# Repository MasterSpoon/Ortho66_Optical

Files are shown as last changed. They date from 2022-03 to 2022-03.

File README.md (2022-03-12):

# Ortho66_Optical
 Ortho 66 Optical PCB using KeyChron low profile optical switches
 
A member on Optical Future discord did trial fit of ir12-21 on switch and will be too close to use.
Took some measurements from a photo I found of a KeyChron PCB and appears they are using 0603 side view IR & PT
Managed to locate some and will need to redo PCB to suit.
Datasheets updated in resources.

This keyboard PCB is a work in progress and has been uploaded to share progress. Schmatic the PCB should be complete however the PCB will need to be updated with the new footprints for 0603 side IR and PT

The footprint's have not yet been tested and will likely be too close to fit correctly.
The code to support the matrix in QMK has not yet been written.
The MCU's are quite hard to obtain at the moment.
Feel free to do with it what you want but I would not suggest getting a PCB made based on the current version.

If you plan to use the footprints in an alternate design there are scripts under the resource folder that will place the supporting components in what I think should be the correct position. Look at the existing schematic for how each part should be named or you can also look at the scripts to get an idea on how they work.

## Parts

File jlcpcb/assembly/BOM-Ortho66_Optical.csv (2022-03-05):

Comment | Designator | Footprint | LCSC
BSS138 | Q1,Q10,Q11,Q12,Q13,Q14,Q2,Q3,Q4,Q5,Q6,Q7,Q8,Q9 | SOT-23 | C112239
100k | R50,R51,R55 | R_0805_2012Metric | C149504
10nF | C11 | C_0402_1005Metric | C15195
100nF | C1,C10,C14,C4,C6,C9 | C_0402_1005Metric | C1525
4.7nF | C13,C15 | C_0402_1005Metric | C1538
10uF | C16 | C_0402_1005Metric | C15525
TYPE-C-31-M12_13 | J1 | USB_C_Receptacle_TYPE-C-31-M-12 | C165948
10K | R47,R56 | R_0805_2012Metric | C17414
150 | R19,R21,R25,R27,R31,R35,R39,R41,R43,R45 | R_0805_2012Metric | C17471
1M | R54 | R_0805_2012Metric | C17514
20 | R1,R10,R11,R14,R15,R16,R17,R2,R5,R6,R7,R8 | R_0805_2012Metric | C17544
2K | R48,R49 | R_0805_2012Metric | C17604
300 | R20,R22,R23,R24,R26,R28,R29,R30,R32,R33,R34,R36,R37,R38,R40,R42,R44,R46 | R_0805_2012Metric | C17617
51 | R12,R13,R18,R3,R4,R9 | R_0805_2012Metric | C17738
4.7uF | C5 | C_0402_1005Metric | C23733
PT12-21B_TR8 | PT1,PT10,PT11,PT12,PT13,PT14,PT15,PT16,PT17,PT18,PT19,PT2,PT20,PT21,PT22,PT23,PT24,PT25,PT26,PT27,PT28,PT29,PT3,PT30,PT31,PT32,PT33,PT34,PT35,PT36,PT37,PT38,PT39,PT4,PT40,PT41,PT42,PT43,PT44,PT45,PT46,PT47,PT48,PT49,PT5,PT50,PT51,PT52,PT53,PT54,PT55,PT56,PT57,PT58,PT59,PT6,PT60,PT61,PT62,PT63,PT64,PT65,PT66,PT7,PT8,PT9 | PT12-21B_TR8 | C264383
USBLC6-2SC6 | U4 | SOT-23-6 | C2687116
5.1k | R52,R53 | R_0805_2012Metric | C27834
DTC123J | Q15 | SOT-23 | C406040
1uF | C12,C2,C3,C7,C8 | C_0402_1005Metric | C52923
IR12-21C_TR8 | IR1,IR10,IR11,IR12,IR13,IR14,IR15,IR16,IR17,IR18,IR19,IR2,IR20,IR21,IR22,IR23,IR24,IR25,IR26,IR27,IR28,IR29,IR3,IR30,IR31,IR32,IR33,IR34,IR35,IR36,IR37,IR38,IR39,IR4,IR40,IR41,IR42,IR43,IR44,IR45,IR46,IR47,IR48,IR49,IR5,IR50,IR51,IR52,IR53,IR54,IR55,IR56,IR57,IR58,IR59,IR6,IR60,IR61,IR62,IR63,IR64,IR65,IR66,IR7,IR8,IR9 | IR12-21C_TR8 | C53672
MCP1700-3302E_SOT23 | U3 | SOT-23 | C5446
RS-1515MBAM | RGB1,RGB10,RGB11,RGB12,RGB13,RGB14,RGB15,RGB16,RGB17,RGB18,RGB19,RGB2,RGB20,RGB21,RGB22,RGB23,RGB24,RGB25,RGB26,RGB27,RGB28,RGB29,RGB3,RGB30,RGB31,RGB32,RGB33,RGB34,RGB35,RGB36,RGB37,RGB38,RGB39,RGB4,RGB40,RGB41,RGB42,RGB43,RGB44,RGB45,RGB46,RGB47,RGB48,RGB49,RGB5,RGB50,RGB51,RGB52,RGB53,RGB54,RGB55,RGB56,RGB57,RGB58,RGB59,RGB6,RGB60,RGB61,RGB62,RGB63,RGB64,RGB65,RGB66,RGB7,RGB8,RGB9 | RS-1515MBAM-RGB_LED-TopRight | C727906
STM32G431KxT_Ux-LQFP32_UFQFPN32 | U1 | LQFP-32_7x7mm_P0.8mm | C730098
CAT24C512WI-GT3 | U5 | SOIC-8_5.23x5.23mm_P1.27mm | C79986
1N4148 | D3,D4,D5,D6 | D_SOD-123 | C81598
1.5A Trip PTC | F1 | Fuse_1812_4532Metric | C84140
SW_Push | RESET1 | K2-1187SQ-A4SW-06 | C92584
IS31FL3743A | U2 | QFN-40-IS31FL3743A_0.2mmClearance
SMF9.0CA | D2 | D_SOD-123
RB060M-60TR | D1 | D_SOD-123

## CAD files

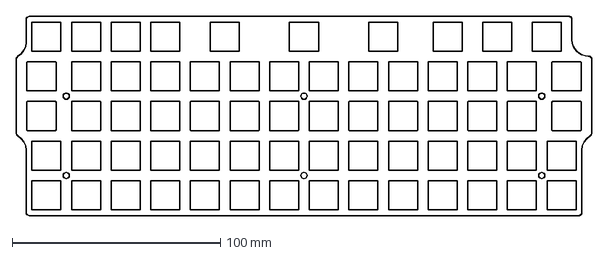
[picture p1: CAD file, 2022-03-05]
resources/Switchplate basic.dxf
276.7 x 95.8 mm

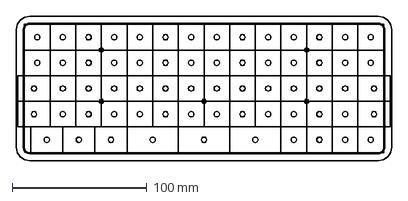
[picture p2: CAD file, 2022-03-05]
resources/PCB Basic.dxf
278.7 x 107.3 mm

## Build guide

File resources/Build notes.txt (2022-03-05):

https://www.aliexpress.com/item/32949070162.html
OD 7.5mm x 2mm thick

Alternative Orings
https://www.aliexpress.com/item/4000150496828.html

Switch to PCB top is 2.4mm - 2.5mm
Minus 1.5-1.6 for switchplate
Space between PCB and switchplate 0.8mm-0.9mm

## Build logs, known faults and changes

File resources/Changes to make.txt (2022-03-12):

Add diode footprints and break out of unused matrix parts - done
Add 3.3v, 5v and GND test points - done
Add logo and revision number - done

Change IR and PT over to 0603 side view
